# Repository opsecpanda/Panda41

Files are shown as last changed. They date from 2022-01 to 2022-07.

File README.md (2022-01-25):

# ***Panda41***

A modified version of the Reviung41 PCB by gtips, designed to fit in a stacked acrylic case made by opsecPANDA in collaboration with dazon. 

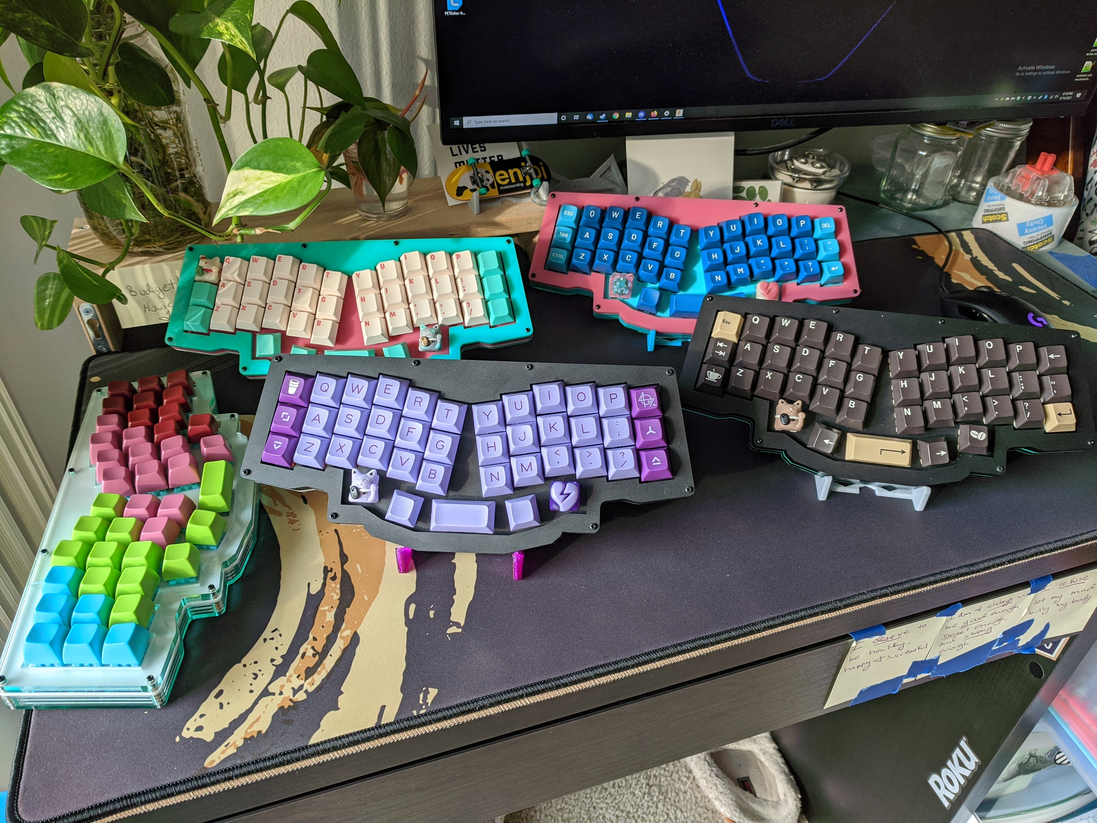
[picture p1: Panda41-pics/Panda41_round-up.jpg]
Panda41 family photo


https://imgur.com/a/qKzNon4

## **PCB**

Modified by dazon and Rossman360, the PCB has the following differences from the original Reviung41:

- Controller footprint rotated and moved underneath a switch
- Top edge of PCB is now flat across
- MX switch footprint
- Diode footprint is THT+SMD combo
- RGB strip header added (SMD LED footprints were not removed)

## **Case**

Case files were designed to each be 3mm acrylic. The files names refer to a number in the beginning to label their order in the stack, and the “--x1” to denote how many of that specific file type you need to have. I.e. “4-mid layer–x2.dxf” means you need to cut or 3D print or otherwise create 2 layers of this one. 

- 1-top top–x1.dxf
- 2-top lower--x1.dxf
- 3-switch plate–x1.dxf
- 4-mid layer with risers–x1.dxf
- 4-mid layer–x2.dxf
- 5-bottom plate–x1.dxf

If you want to mimic my original “top color & bottom color” mix&match, you want to have layers 1 and 2 be Color A and, the remainders be Color B. If you want to do an “RGB layer” you should actually have both “4-mid layer–x2.dxf” layers be something like white, off-white, opal, glass or just clear. 

## **Hardware**

The case is designed to use the following hardware:

- 16 m2 case screws - 8mm length
- 8 m2 case spacers - 10mm length
- 3 m2 riser nuts
- 3 m2 riser screws - 12mm length
- 41 diodes - 1N4148, through hole (TR) or SMD
- 1 tactile reset switch - PTS635SH43LFS

## **Firmware/keymap:**

When flashing for this board, you want to treat it as a Reviung41. You can create a keymap with the online QMK Configurator under the Reviung41 selection. If you want to use VIA, flash it with the “reviung41_via.hex”.  You can use a nice!nano and flash with a reviung41 shield. 

## Brief Build Guide 

1. Flash controller, make sure it’s detecting properly as a reviung41.
2. Solder diodes and reset switch. Black line on diode points towards square pad on PCB. Reset switch does not have directionality.
3. Solder LEDs or LED strip if you're using any.
4. Solder controller pins or controller hotswap sockets to the keyboard PCB. **Do not solder the *CONTROLLER* yet, just the pins.**
5. Put your switches in the switch plate and solder them to the PCB.
6. Solder controller. Check the image below to confirm the controller orientation is correct before you solder.
7. Assemble case.

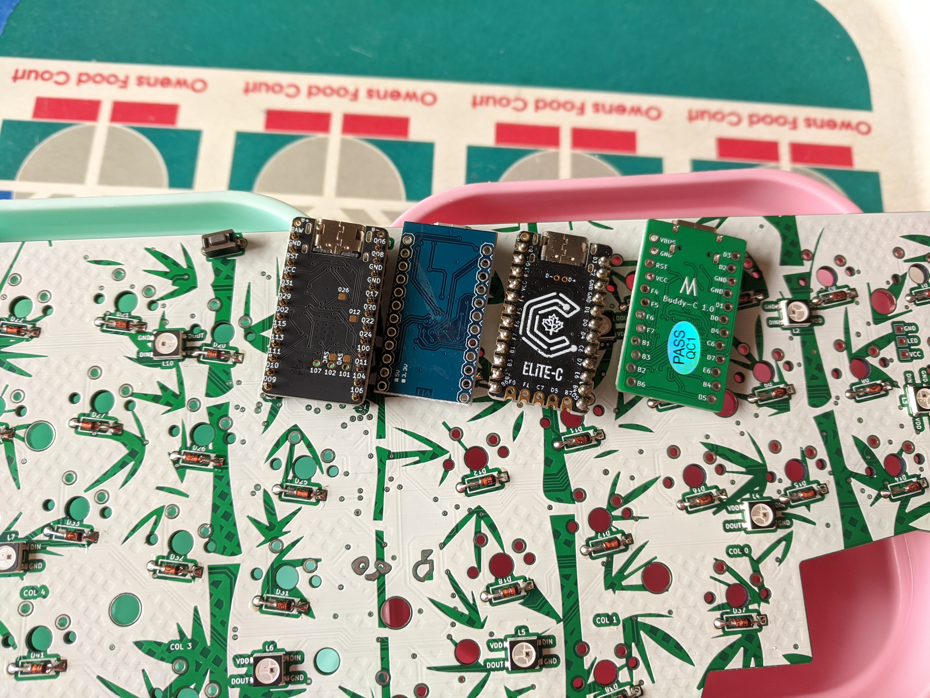
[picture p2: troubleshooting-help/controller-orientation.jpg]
Controller Orientation


#### Contact me

You can contact me via Discord (opsecPANDA#8008) or Reddit (u/opsecpanda) or email me at opsecpanda.blue@gmail.com.

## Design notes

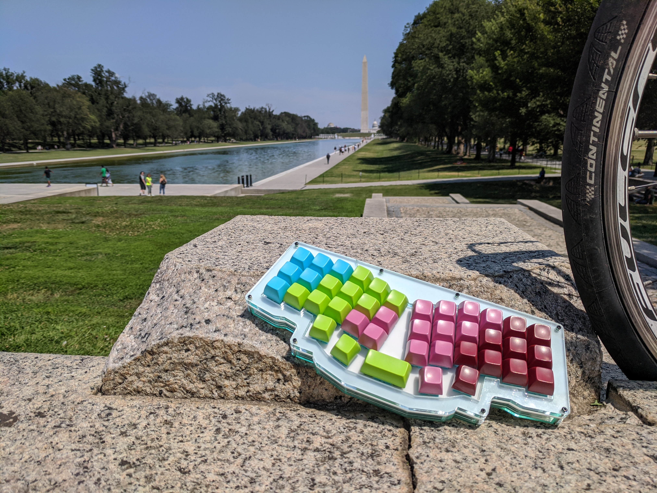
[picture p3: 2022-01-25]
Panda41-pics/sa at monuments.jpg

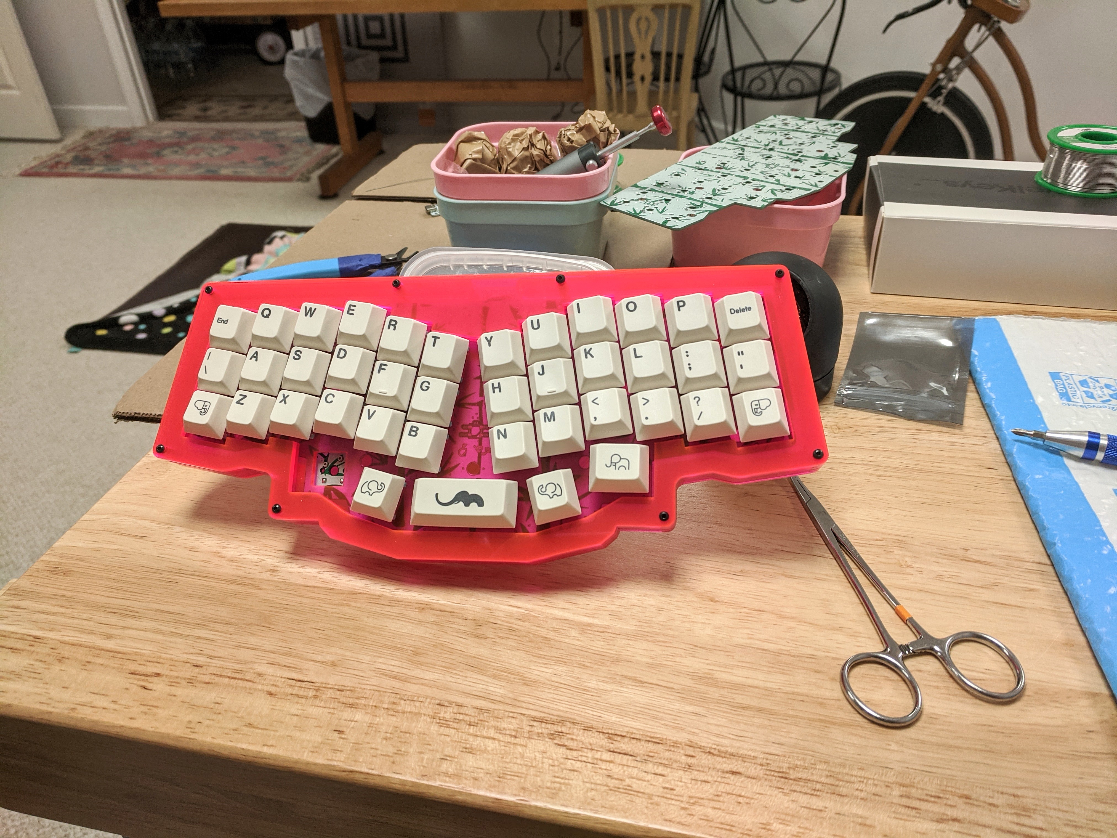
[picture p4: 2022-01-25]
Panda41-pics/neon pink translucent.jpg

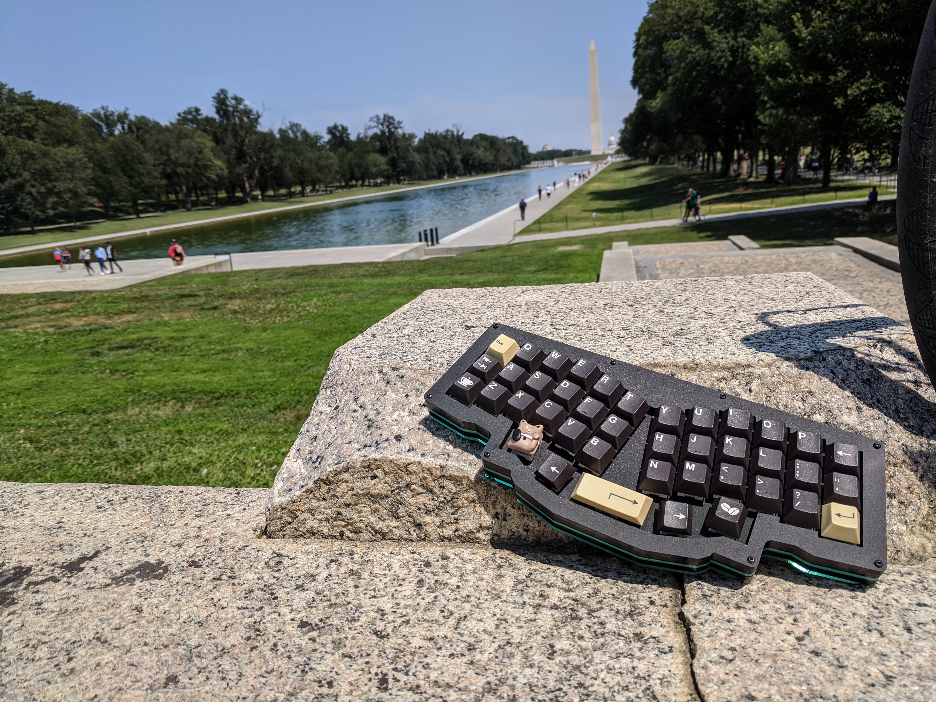
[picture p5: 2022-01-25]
Panda41-pics/cafe at monuments.jpg

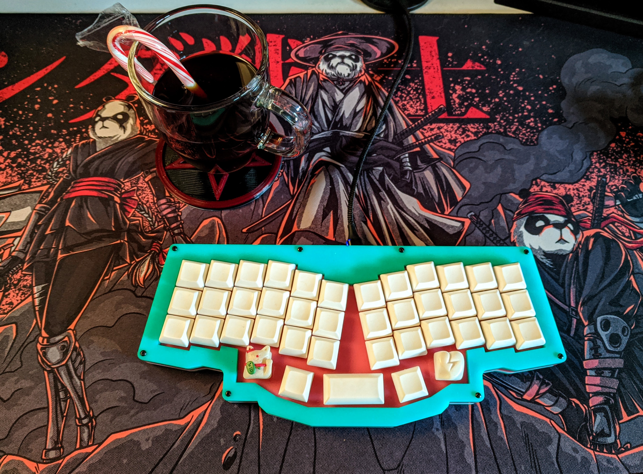
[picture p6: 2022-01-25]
Panda41-pics/HuB.jpg

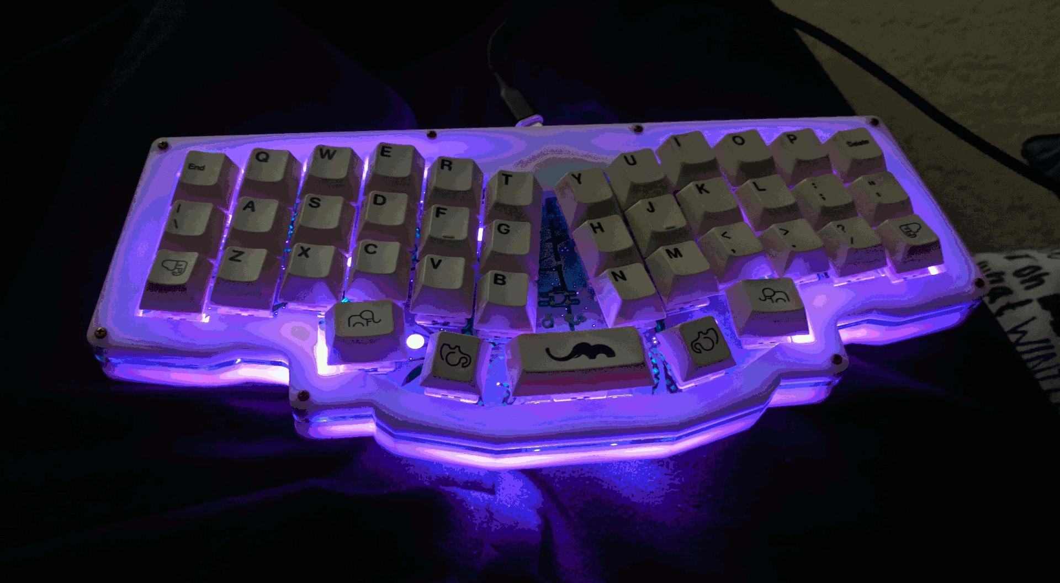
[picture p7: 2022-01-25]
Panda41-pics/rainbow_panda41.gif

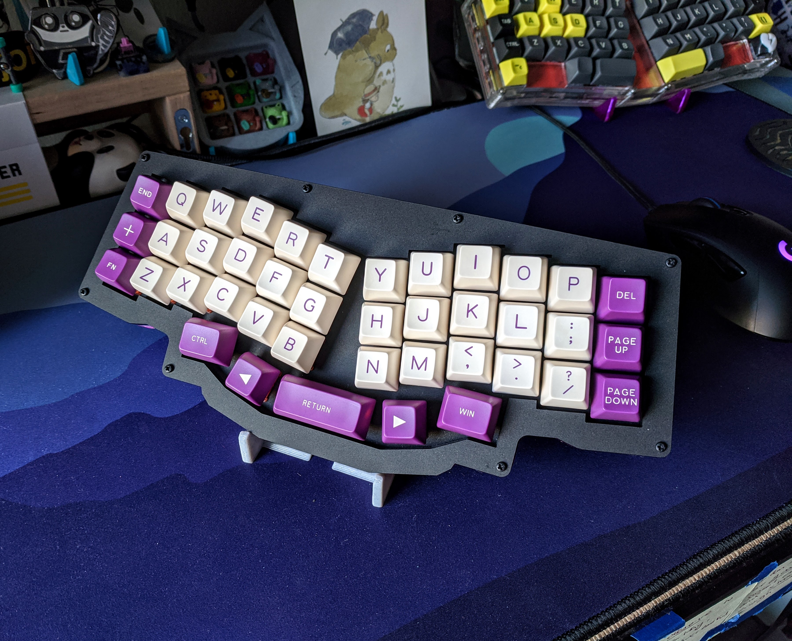
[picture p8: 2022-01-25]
Panda41-pics/SA Maxkey violet on cream.jpg

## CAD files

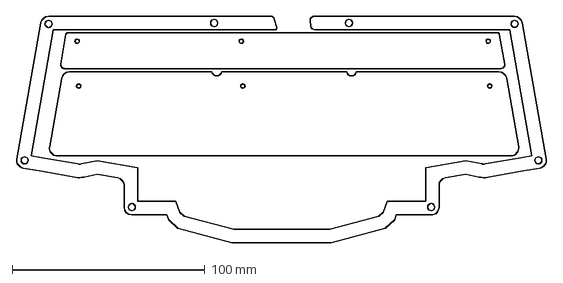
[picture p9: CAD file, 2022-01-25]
case-files/4-mid layer with risers--x1.dxf
275.3 x 117.6 mm

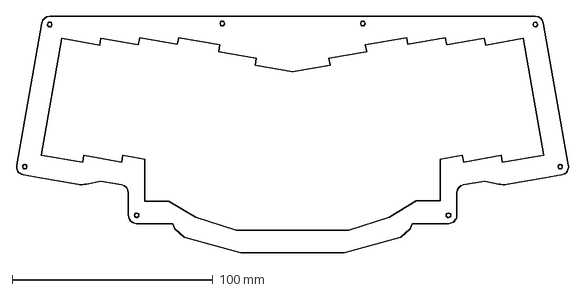
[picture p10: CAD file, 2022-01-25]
case-files/1-top top--x1.dxf
275.3 x 117.6 mm

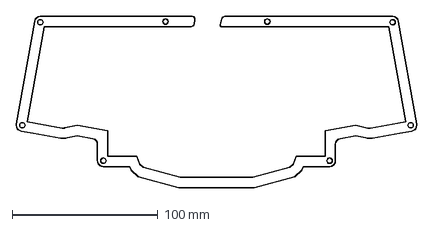
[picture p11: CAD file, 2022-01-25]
case-files/4-mid layer--x2.dxf
275.3 x 117.6 mm

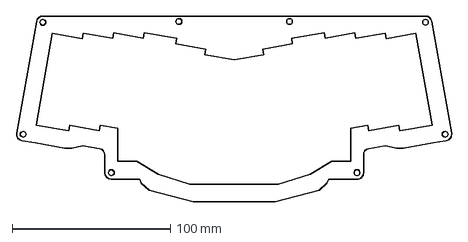
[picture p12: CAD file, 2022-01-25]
case-files/2-top lower--x1.dxf
275.5 x 117.6 mm

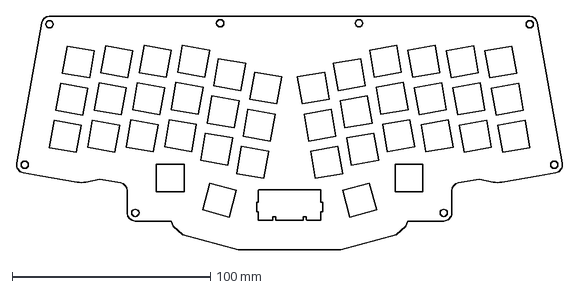
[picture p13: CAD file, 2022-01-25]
case-files/3-switch plate--x1.dxf
275.3 x 117.6 mm

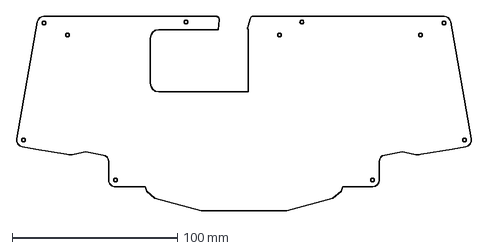
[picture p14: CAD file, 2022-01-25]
case-files/5-bottom plate--x1.dxf
275.3 x 117.6 mm

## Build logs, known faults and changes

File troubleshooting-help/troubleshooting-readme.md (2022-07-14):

## Controller Orientation Examples

Controller Orientation

## Panda41 - column pin layout

#### Remember: this key matrix testing  image is correct when you are looking at the *top* of the PCB. It will be mirrored if you perform testing from the bottom of the PCB. 

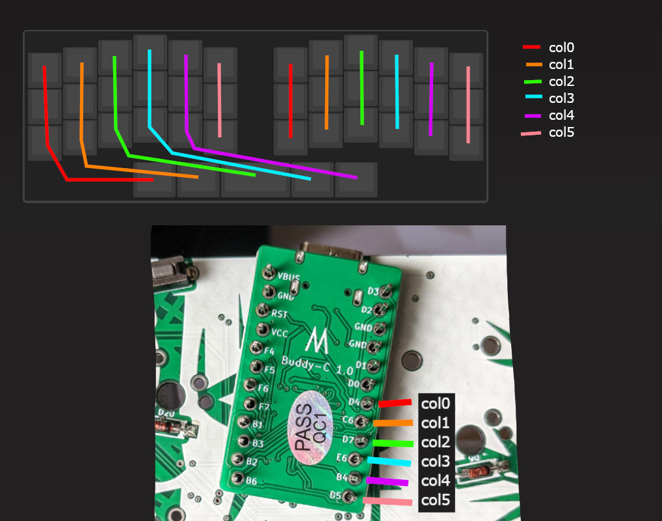
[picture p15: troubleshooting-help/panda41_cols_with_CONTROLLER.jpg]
Panda41 - column pin layout


## Panda41 - row pin layout

#### Remember: this key matrix testing image is correct when you are looking at the *top* of the PCB. It will be mirrored if you perform testing from the bottom of the PCB.

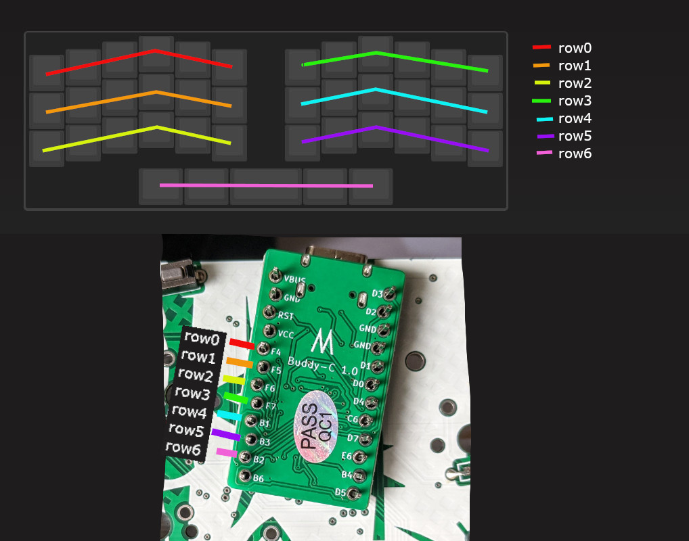
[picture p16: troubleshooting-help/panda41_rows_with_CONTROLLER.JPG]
Panda41 - row pin layout


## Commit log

2022-01-25 File editing - cleaning up
    [1-top top--x1.dxf, 2-top lower--x1.dxf, 3-switch plate--x1.dxf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]
2022-01-25 renaming folders
    [1-top top--x1.dxf, 2-top lower--x1.dxf, 3-switch plate--x1.dxf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]
